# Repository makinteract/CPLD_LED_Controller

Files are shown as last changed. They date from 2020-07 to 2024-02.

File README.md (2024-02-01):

# BlinkBoard

This repository contains the hardware design of [BlinkBoard](https://blinkboard.kaist.ac.kr). An examples of software that integrates with this hardware can be found [here](https://github.com/makinteractlab/BlinkBoardApp).

This hardware is open source under the MIT license.

---

## Command Line Interface usage

This is the list of all the possible comamnds.

### Help

You can simply type `help` or use the following command to see a list of all the possible supported commands:

```js
{"cmd": "help"}  // see all supported commands
```

### Check status

Check if ready.

```js
{"cmd": "status"}    // request
{"status": "ready"}  // answer
```

### Check formware version

Check activation by passing the current month and year and see if it is <= of activation date

```js
{"cmd": "version"}  // check activateion in September 2020
{"version": "1.0"}  // answer
```

### Reset

Reset LED and outputs

```js
{"cmd": "reset"}
{"ack": "reset"}
```

### Get Input

Read A0, A1, A2 using specific number of samples (default 1 max 50);

```js
{"cmd": "analogRead"}                       // request (default samples = 1)
{"cmd": "analogRead", "samples": "5"}       // request

{"ack":"analogRead", "A0":343, "A1":371, "A2":364}  // example answer
```

### Set output

Set voltage between 0V and 4.5V on **D2**. The input value and the return voltage are clipped between 0 and 4.5V.

```js
{"cmd": "setV", "value" : "4000"}     // request
{"ack": "voltage", "value": 4000}     // answer

//clipping example
{"cmd": "setV", "value" : "5000"}     // request
{"ack": "voltage", "value": 4500}     // answer
```

**D0** and **D1** can be set HIGH/LOW or PWM.

```js
{"cmd": "setHigh", "pin": "D0"}       // request
{"cmd": "setLow", "pin": "D0"}        // request

{"ack": "setHigh", "pin": "D0"}       // answer
{"ack": "setLow", "pin": "D0"}        // answer
```

For PWM the input duty and the return voltage are clipped between 0 and 100. Pin can be **D0** or **D1**.

```js
{"cmd": "setPwm", "pin": "D0", "duty" : "90"}       // request
{"ack": "setPwm", "pin": "D0", "duty" : 90}         // answer

// clipping example
{"cmd": "setPwm", "pin": "D0", "duty" : "120"}     // request
{"ack": "setPwm", "pin": "D0", "duty" : 100}       // answer
```

### LEDs patterns

LEDs are placed in this config

```
1 -- 26
2 -- 27
3 -- 28
4 -- 29
. -- .
. -- .
. -- .
23 -- 48
24 -- 49
25 -- 50
```

Patterns:

- off
- on = steady on
- blink
- blink2 = 1/2 of blink

```js
{"cmd": "setLed", "led": "1", "pattern": "off"}
{"cmd": "setLed", "led": "1", "pattern": "on"}
{"cmd": "setLed", "led": "1", "pattern": "blink"}
{"cmd": "setLed", "led": "1", "pattern": "blink2"}

{"ack": "setLed", "led": "1", "pattern": "off"}
{"ack": "setLed", "led": "1", "pattern": "on"}
{"ack": "setLed", "led": "1", "pattern": "blink"}
{"ack": "setLed", "led": "1", "pattern": "blink2"}
```

### Set LedCmd

```js
{"cmd": "setCmdLed", "led": "vcc", "pattern": "on"}
{"cmd": "setCmdLed", "led": "gnd", "pattern": "on"}
{"cmd": "setCmdLed", "led": "a0", "pattern": "on"}
{"cmd": "setCmdLed", "led": "a1", "pattern": "on"}
{"cmd": "setCmdLed", "led": "a2", "pattern": "on"}
{"cmd": "setCmdLed", "led": "d0", "pattern": "on"}
{"cmd": "setCmdLed", "led": "d1", "pattern": "on"}
{"cmd": "setCmdLed", "led": "d2", "pattern": "on"}
{"cmd": "setCmdLed", "led": "status1", "pattern": "on"}
{"cmd": "setCmdLed", "led": "status2", "pattern": "on"}
```

### Brightness

Values of brightness between 0 and 99

```js
{"cmd": "setBrightness", "value": "1"}
{"ack": "brightness", "value": "1"}

// clipping example
{"cmd": "setBrightness", "value": "120"}
{"ack": "brightness", "value": "100"}
```

### Animate LEDs

Draw all LEDs 1-50 and vice-versa

```js
{"cmd": "animate"}
{"ack": "animate"}

// optionally put time in ms
{"cmd": "animate", value:"100"}
{"ack": "animate"}
```

### Others

Other errors

```js
{"ack":"json parse fail"}   // not valid JSON input
{"ack":"invalid command"}   // not valid command
```

---

## Hardware description

For details about the hardware design refer to the [electronic schematics](https://github.com/makinteractlab/BlinkBoard/blob/master/Altium/BlinkBoard/Project%20Outputs%20for%20BlinkBoard/BlinkBoard.PDF).

For details about how to assemble this hardware, please refer to the Hardware X paper (_link available after publication_) and the following building instructions.

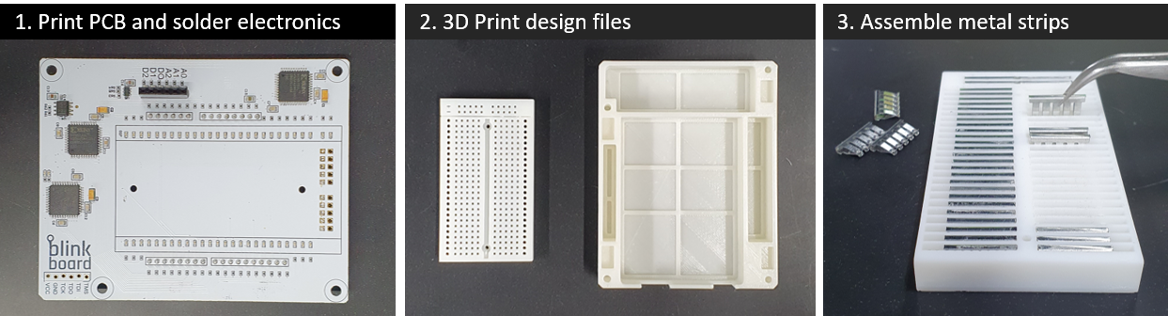
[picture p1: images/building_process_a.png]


- **Step 1**: The first step is to print the _BlinkBoard_ PCB shield using the supplied GERBER files and manually solder/assemble electronic components onto the printed shield. If placing an order from a manufacturer with a pick-and-place machine, provide them with the assembly instructions and the BOM file.
- **Step 2**: 3D print the breadboard and the case using the STL files. For better resolution/precision of the pinholes of the breadboard, it is recommended to print the model with ABS-like white resin (Accura Xtreme White 200) via an SLA (Stereolithography) 3D printer. However, the bottom case can be printed simply with PLA (PolyLactic Acid) using a Fused Deposition Modeling (FDM) machine, ensuring low cost and strength.

- **Step 3**: Assemble the metal clips placed underneath the breadboard to connect 2 four-hole female sockets on a row. These metal clips can be obtained by manually disassembling a 400-hole breadboard (e.g., Breadboard DM323).

- **Step 4**: Place the breadboard on the shield and use two M1.6 8mm bolts and nuts to tighten them.

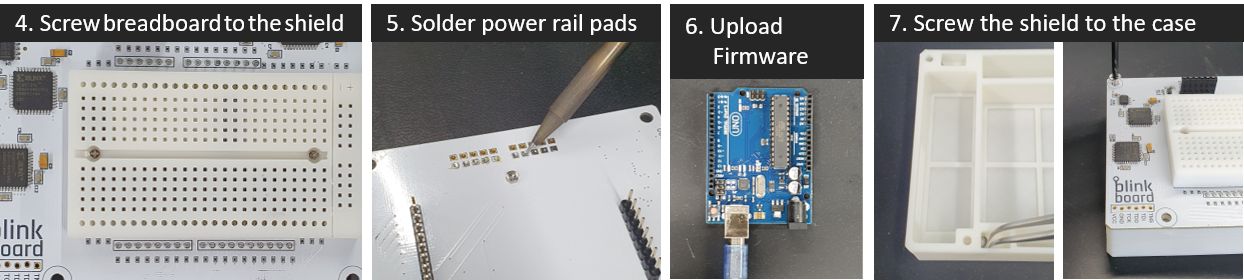
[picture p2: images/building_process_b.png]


- **Step 5**: Solder the ground rail on the bottom to share all the grounds on the _BlinkBoard_ shield. Make sure the ground socket of the breadboard is connected to this rail.

- **Step 6**: Before connecting the shield to an Arduino, upload the firmware via USB.

- **Step 7**: Insert the M3 nuts inside the housing slots of the case and fix the shield on the top of the 3D printed case using the M3 12mm bolts.

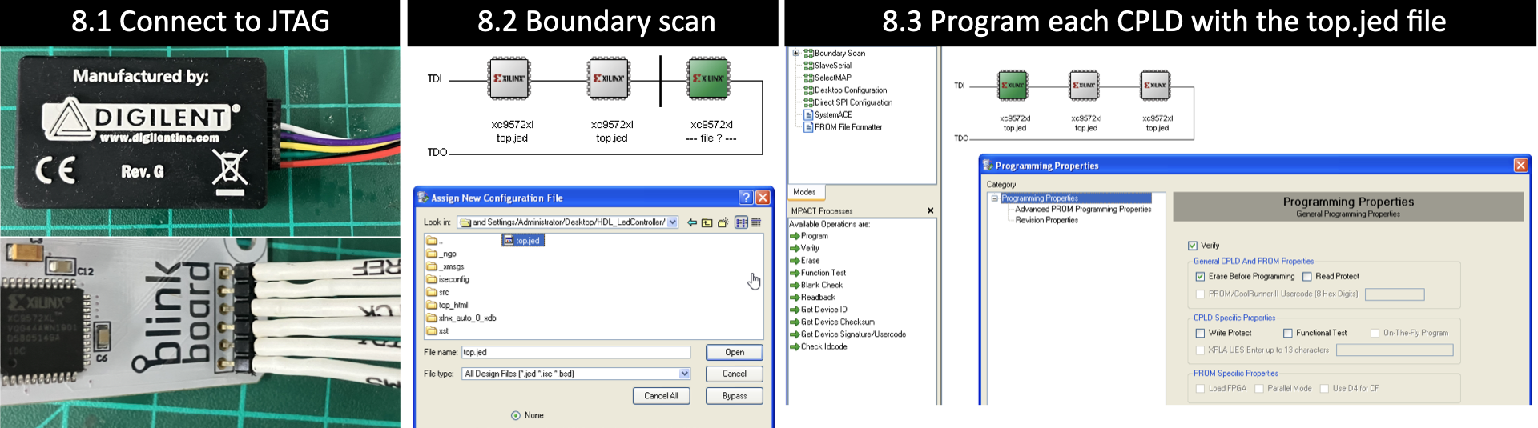
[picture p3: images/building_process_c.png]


- **Step 8**: Generate the bitstream file from the hardware-description specifications (i.e. Verilog files) using the Xilinx ISE Design Suite and upload it via JTAG on each of the CPLDs. This step can be broken down into the following sub-steps:

  1. Power up the assembled BlinkBoard hardware by plugging it into a computer via USB. Connect BlinkBoard to the [XUP USB-JTAG Programming Cable](https://digilent.com/shop/xup-usb-jtag-programming-cable/) as shown in Figure 8.

  2. 8.2: On a PC opens the application iMPACT by Xilinx. This should automatically prompt for a boundary scanning of the connected devices, and ask to choose a file to upload to the CPLDs. Simply pick the `top.jed` file in the repository, or use the ISE Design Suite to regenerate a bitstream from the source Verilog files (HDL_LedController folder). For the success of this step, ensure that the JTAG is properly connected and that the BlinkBoard is powered up.

  3. The icons of three CPLDs connected in series should be visible on the GUI. Select each one of them and click the "Program" button on the left panel to upload the bitstream on the CPLDs.

---

## References

Controlling LEDs using the [CoolRunner-II][product]. [Schematics][schematics] and [datasheet][datasheet] are provided in the links for reference.

---

## Citation

Andrea Bianchi, Kongpyung Justin Moon, Artem Dementyev, Seungwoo Je. 2024. _BlinkBoard: Guiding and monitoring circuit assembly for synchronous and remote physical computing education_. In HardwareX 2024, e00511, ISSN 2468-0672, DOI: [https://doi.org/10.1016/j.ohx.2024.e00511](https://doi.org/10.1016/j.ohx.2024.e00511).

<!-- REFERENCES -->

[product]: https://store.digilentinc.com/cmod-c2-breadboardable-coolrunner-ii-cpld-module/
[schematics]: https://reference.digilentinc.com/_media/cmod:cmod:c-mod_c295_sch.pdf
[datasheet]: https://reference.digilentinc.com/_media/cmod:cmod:cmod_rm.pdf

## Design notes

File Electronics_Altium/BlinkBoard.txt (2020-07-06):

Board Information Report
Filename     : C:\Users\Andrea\GIT\BlinkBoard\Altium\BlinkBoard\BlinkBoard.PcbDoc
Date         : 7/6/2020
Time         : 1:06:12 PM
Time Elapsed : 00:00:00

General
    Board Size, 496.316mmx149.225mm
    Components on board, 21
count : 2

Routing Information
    Routing completion, 0.00%
    Connections, 48
    Connections routed, 0
    Connections remaining, 48
count : 4

Layer, Arcs, Pads, Vias, Tracks, Texts, Fills, Regions, ComponentBodies
    Top Layer, 25, 34, 0, 0, 0, 0, 0, 0
    Int1 (GND), 0, 0, 0, 4, 0, 0, 1, 0
    Inner Sig, 0, 0, 0, 0, 0, 0, 0, 0
    Bottom Layer, 0, 0, 0, 0, 0, 0, 0, 0
    Mechanical 1, 4, 0, 0, 0, 0, 0, 0, 13
    Mechanical 2, 226, 0, 0, 104, 14, 0, 0, 0
    Multi-Layer, 0, 70, 0, 0, 0, 0, 1, 0
    Top Paste, 0, 0, 0, 0, 0, 0, 0, 0
    Top Overlay, 6, 0, 0, 84, 48, 0, 0, 0
    Top Solder, 0, 0, 0, 0, 0, 0, 0, 0
    Bottom Solder, 0, 0, 0, 0, 0, 0, 0, 0
    Bottom Overlay, 0, 0, 0, 0, 0, 0, 0, 0
    Bottom Paste, 0, 0, 0, 0, 0, 0, 0, 0
    Drill Guide, 0, 0, 0, 0, 0, 0, 0, 0
    Keep-Out Layer, 0, 0, 0, 0, 0, 0, 0, 0
    Drill Drawing, 0, 0, 0, 0, 0, 0, 0, 0
count : 16

Drill Pairs, Vias
count : 0

Non-Plated Hole Size, Pads, Vias
    2mm, 2, 0
    3.2mm, 4, 0
count : 2

Plated Hole Size, Pads, Vias
    0mm, 34, 0
    0.9mm, 32, 0
    1.1mm, 12, 0
    1.2mm, 20, 0
count : 4

Non-Plated Slot Size / Length, Pads
count : 0

Plated Slot Size / Length, Pads
count : 0

Non-Plated Square Hole Size, Pads
count : 0

Plated Square Hole Size, Pads
count : 0

Top Layer Annular Ring Size, Count
    0mm, 6
    0.4mm, 20
    0.5mm, 12
    0.6mm, 32
count : 4

Mid Layer Annular Ring Size, Count
    0mm, 6
    0.4mm, 20
    0.5mm, 12
    0.6mm, 32
count : 4

Bottom Layer Annular Ring Size, Count
    0mm, 6
    0.4mm, 20
    0.5mm, 12
    0.6mm, 32
count : 4

Pad Solder Mask, Count
    0.02mm, 30
    0.1016mm, 74
count : 2

Pad Paste Mask, Count
    0mm, 104
count : 1

Pad Pwr/Gnd Expansion, Count
    0.508mm, 104
count : 1

Pad Relief Conductor Width, Count
    0.254mm, 104
count : 1

Pad Relief Air Gap, Count
    0.254mm, 104
count : 1

Pad Relief Entries, Count
    4, 104
count : 1

Via Solder Mask, Count
count : 0

Track Width, Count
    0.08mm, 5
    0.09mm, 5
    0.1mm, 52
    0.2mm, 99
    0.5mm, 27
    1.016mm, 4
count : 6

Arc Line Width, Count
    0.08mm, 1
    0.1mm, 8
    0.2mm, 251
    1mm, 1
count : 4

Arc Radius, Count
    0.1047mm, 1
    0.2mm, 1
    0.3175mm, 1
    0.5756mm, 250
    3.7mm, 8
count : 5

Arc Degrees, Count
    180, 1
    205, 1
    360, 259
count : 3

Text Height, Count
    0.5mm, 5
    0.8mm, 1
    1mm, 3
    1.524mm, 42
    2mm, 10
    3mm, 1
count : 6

Text Width, Count
    0.1mm, 5
    0.15mm, 15
    0.254mm, 42
count : 3

Net Track Width, Count
    0.254mm, 27
count : 1

Net Via Size, Count
    1.27mm, 27
count : 1

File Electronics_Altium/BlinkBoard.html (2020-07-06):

Altium customize

# Board Information Report

Date: | | 7/6/2020
Time: | | 1:06:12 PM
Elapsed Time: | | 00:00:00
Filename: | | C:\Users\Andrea\GIT\BlinkBoard\Altium\BlinkBoard\BlinkBoard.PcbDoc
Units: | | mmmils

## Contents

Contents

Board Specification

General

Routing

Routing Information

Layer Information

Layer Information

Drill Pairs

Board Holes

Non-Plated Hole Size

Plated Hole Size

Board Slots

Non-Plated Slot Size

Plated Slot Size

Board Square Holes

Non-Plated Square Hole Size

Plated Square Hole Size

Other

Top Layer Annular Ring Size

Mid Layer Annular Ring Size

Bottom Layer Annular Ring Size

Pad Solder Mask

Pad Paste Mask

Pad Pwr/Gnd Expansion

Pad Relief Conductor Width

Pad Relief Air Gap

Pad Relief Entries

Via Solder Mask

Track Width

Arc Line Width

Arc Radius

Arc Degrees

Text Height

Text Width

Net Track Width

Net Via Size

## Board Specification

General
Board Size | 496.316mm x 149.225mm
Components on board | 21

Back to top

## Routing

Routing Information
Routing completion | 0.00%
Connections | 48
Connections routed | 0
Connections remaining | 48

Back to top

## Layer Information

Layer | Arcs | Pads | Vias | Tracks | Texts | Fills | Regions | ComponentBodies
Top Layer | 25 | 34 | 0 | 0 | 0 | 0 | 0 | 0
Int1 (GND) | 0 | 0 | 0 | 4 | 0 | 0 | 1 | 0
Inner Sig | 0 | 0 | 0 | 0 | 0 | 0 | 0 | 0
Bottom Layer | 0 | 0 | 0 | 0 | 0 | 0 | 0 | 0
Mechanical 1 | 4 | 0 | 0 | 0 | 0 | 0 | 0 | 13
Mechanical 2 | 226 | 0 | 0 | 104 | 14 | 0 | 0 | 0
Multi-Layer | 0 | 70 | 0 | 0 | 0 | 0 | 1 | 0
Top Paste | 0 | 0 | 0 | 0 | 0 | 0 | 0 | 0
Top Overlay | 6 | 0 | 0 | 84 | 48 | 0 | 0 | 0
Top Solder | 0 | 0 | 0 | 0 | 0 | 0 | 0 | 0
Bottom Solder | 0 | 0 | 0 | 0 | 0 | 0 | 0 | 0
Bottom Overlay | 0 | 0 | 0 | 0 | 0 | 0 | 0 | 0
Bottom Paste | 0 | 0 | 0 | 0 | 0 | 0 | 0 | 0
Drill Guide | 0 | 0 | 0 | 0 | 0 | 0 | 0 | 0
Keep-Out Layer | 0 | 0 | 0 | 0 | 0 | 0 | 0 | 0
Drill Drawing | 0 | 0 | 0 | 0 | 0 | 0 | 0 | 0
Total | 261 | 104 | 0 | 192 | 62 | 0 | 2 | 13

Back to top

Drill Pairs | Vias
Total | 0

Back to top

## Board Holes

Non-Plated Hole Size | Pads | Vias
2mm | 2 | 0
3.2mm | 4 | 0
Total | 6 | 0

Back to top

Plated Hole Size | Pads | Vias
0mm | 34 | 0
0.9mm | 32 | 0
1.1mm | 12 | 0
1.2mm | 20 | 0
Total | 98 | 0

Back to top

## Board Slots

Non-Plated Slot Size / Length | Pads
Total | 0

Back to top

Plated Slot Size / Length | Pads
Total | 0

Back to top

## Board Square Holes

Non-Plated Square Hole Size | Pads
Total | 0

Back to top

Plated Square Hole Size | Pads
Total | 0

Back to top

## Other

Top Layer Annular Ring Size | Count
0mm | 6
0.4mm | 20
0.5mm | 12
0.6mm | 32
Total | 70

Back to top

Mid Layer Annular Ring Size | Count
0mm | 6
0.4mm | 20
0.5mm | 12
0.6mm | 32
Total | 70

Back to top

Bottom Layer Annular Ring Size | Count
0mm | 6
0.4mm | 20
0.5mm | 12
0.6mm | 32
Total | 70

Back to top

Pad Solder Mask | Count
0.02mm | 30
0.1016mm | 74
Total | 104

Back to top

Pad Paste Mask | Count
0mm | 104
Total | 104

Back to top

Pad Pwr/Gnd Expansion | Count
0.508mm | 104
Total | 104

Back to top

Pad Relief Conductor Width | Count
0.254mm | 104
Total | 104

Back to top

Pad Relief Air Gap | Count
0.254mm | 104
Total | 104

Back to top

Pad Relief Entries | Count
4 | 104
Total | 104

Back to top

Via Solder Mask | Count
Total | 0

Back to top

Track Width | Count
0.08mm | 5
0.09mm | 5
0.1mm | 52
0.2mm | 99
0.5mm | 27
1.016mm | 4
Total | 192

Back to top

Arc Line Width | Count
0.08mm | 1
0.1mm | 8
0.2mm | 251
1mm | 1
Total | 261

Back to top

Arc Radius | Count
0.1047mm | 1
0.2mm | 1
0.3175mm | 1
0.5756mm | 250
3.7mm | 8
Total | 261

Back to top

Arc Degrees | Count
180 | 1
205 | 1
360 | 259
Total | 261

Back to top

Text Height | Count
0.5mm | 5
0.8mm | 1
1mm | 3
1.524mm | 42
2mm | 10
3mm | 1
Total | 62

Back to top

Text Width | Count
0.1mm | 5
0.15mm | 15
0.254mm | 42
Total | 62

Back to top

Net Track Width | Count
0.254mm | 27
Total | 27

Back to top

Net Via Size | Count
1.27mm | 27
Total | 27

Back to top

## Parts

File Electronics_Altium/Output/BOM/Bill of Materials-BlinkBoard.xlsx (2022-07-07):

Designator | Packaging | Supplier Part Number 1 | Comment | Description | Manufacturer 1 | Manufacturer Part Number 1 | Quantity | Supplier Currency 1 | Supplier Order Qty 1 | Supplier Unit Price 1
C1, C2, C3 | Tape and Reel | 399-3688-6-ND | 100u | 100uF Solid MnO2 Tantalum Capacitor, 4 V +/-20%, T491 Series | KEMET | T491A107M004AT | 3 | USD | 3 | 0.73
C4, C5, C6, C7, C8, C9, C10, C11, C12 | Tape and Reel | 311-3553-6-ND | 47n | Cap Ceramic 0.047uF 50V X7R 5% SMD 0805 125C Paper T/R | Yageo | CC0805JRX7R9BB473 | 9 | USD | 9 | 0.17
C13, C16 | Tape and Reel | 311-1358-6-ND | 1u | CERAMIC CAPACITOR, 1UF, 25V, Y5V, +80, -20%, 0805, FULL REEL; Product Range:CC Series; Capacitance:1 F; Capacitance Tolerance:+80%, -20%; Dielectric Characteristic:Y5V; Voltage Rating:25V; Ceramic Capacitor Case:0805 [2012 Metric] ;RoHS Compliant: Yes | Yageo | CC0805ZRY5V8BB105 | 2 | USD | 2 | 0.14
C14 | Tape and Reel | 311-1703-6-ND | 10n | Cap Ceramic 0.01uF 10V X7R 10% SMD 0402 125C Paper T/R | Yageo | CC0402KRX7R6BB103 | 1 | USD | 1 | 0.1
C15 | Tape and Reel | 311-2084-6-ND | 10u | Cap Ceramic 10uF 6.3V X5R 10% SMD 0805 85C Paper T/R | Yageo | CC0805KRX5R5BB106 | 1 | USD | 1 | 0.21
D1, D2, D3, D4, D5, D6, D7, D8, D9, D10, D11, D12, D13, D14, D15, D16, D17, D18, D19, D20, D21, D22, D23, D24, D25, D26, D27, D28, D29, D30, D31, D32, D33, D34, D35, D36, D37, D38, D39, D40, D41, D42, D43, D44, D45, D46, D47, D48, D49, D50, D51, D52, D53, D54, D55, D56, D57, D58, D59, D60 | Tape and Reel | VLMS1500-GS08DKR-ND | LED0402_RED | Led red | Vishay | VLMS1500-GS08 | 60 | USD | 60 | 0.322
R1, R2, R3, R4, R5, R6, R7, R8, R9, R10, R11, R12, R13, R14, R15, R16, R17, R18, R19, R20, R21, R22, R23, R24, R25, R26, R27, R28, R29, R30, R31, R32, R33, R34, R35, R36, R37, R38, R39, R40, R41, R42, R43, R44, R45, R46, R47, R48, R49, R50, R51, R52, R53, R54, R55, R56, R57, R58, R59, R60 | Tape and Reel | 311-62.0LRDKR-ND | 62 | RES SMD 62 OHM 1% 1/16W 0402 | Yageo | RC0402FR-0762RL | 60 | USD | 60 | 0.016
R61 | Tape and Reel | 311-47KJRDKR-ND | 47k | YAGEO - RC0402JR-0747KL - SMD Chip Resistor, 0402 [1005 Metric], 47 kohm, RC Series, 50 V, Thick Film, 63 mW | Yageo | RC0402JR-0747KL | 1 | USD | 1 | 0.1
R62 | Tape and Reel | 311-120KJRDKR-ND | 120k | RES SMD 120K OHM 5% 1/16W 0402 | Yageo | RC0402JR-07120KL | 1 | USD | 1 | 0.1
R63, R64, R65 | Tape and Reel | YAG1249DKR-ND | 10k | RES SMD 10K OHM 1% 1/16W 0402 | Yageo | RC0402FR-0710KP | 3 | USD | 3 | 0.1
U1, U2, U3 | Tray | 122-1448-ND | XC9572XL-10VQG44C | XILINX - XC9572XL-10VQG44C. - CPLD, 72 MACROCELL, 3.3V, 44VQFP | Xilinx | XC9572XL-10VQG44C | 3
U4 | Tape and Reel | 296-6501-6-ND | NE555DR | TEXAS INSTRUMENTS NE555DR. TIMER, SINGLE, 500KHZ, 16V, SOIC-8 | Texas Instruments | NE555DR | 1 | USD | 1 | 0.46
U5 | Tape and Reel | MCP4725A0T-E/CHDKR-ND | MCP4725A0T-E/CH (2) | DAC 1-CH Resistor-String 12-bit 6-Pin SOT-23A T/R | Microchip | MCP4725A0T-E/CH | 1 | USD | 1 | 1.28

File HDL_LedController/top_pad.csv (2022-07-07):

Release 8.1i - Fit P.20131013
Copyright(c) 1995-2003 Xilinx Inc. All rights reserved
7- 7-2022 4:23PM
NOTE: This file is designed to be imported into a spreadsheet program
such as Microsoft Excel for viewing | printing and sorting. The comma ' | '
character is used as the data field separator.
This file is also designed to support parsing.
Input file: top.ngd
output file: top_pad.csv
Part type: xc9572xl
Speed grade: -5
Package: vq44
Pinout by Pin Number:
----- | ----- | ----- | ----- | ----- | ----- | ----- | ----- | ----- | -----
Pin Number | Signal Name | Pin Usage | Pin Name | Direction | IO Standard | IO Bank Number | {blank} | Slew Rate | Termination | {blank} | Voltage | Constraint
P1 | TIE |  | I/O/GCK3
P2 | LED<19> | O | I/O | OUTPUT
P3 | LED<18> | O | I/O | OUTPUT
P4 | GND |  | GND
P5 | LED<17> | O | I/O | OUTPUT
P6 | LED<16> | O | I/O | OUTPUT
P7 | LED<15> | O | I/O | OUTPUT
P8 | LED<14> | O | I/O | OUTPUT
P9 | TDI |  | TDI
P10 | TMS |  | TMS
P11 | TCK |  | TCK
P12 | LED<13> | O | I/O | OUTPUT
P13 | LED<12> | O | I/O | OUTPUT
P14 | LED<11> | O | I/O | OUTPUT
P15 | VCC |  | VCCINT
P16 | LED<10> | O | I/O | OUTPUT
P17 | GND |  | GND
P18 | LED<9> | O | I/O | OUTPUT
P19 | LED<8> | O | I/O | OUTPUT
P20 | LED<7> | O | I/O | OUTPUT
P21 | LED<6> | O | I/O | OUTPUT
P22 | LED<5> | O | I/O | OUTPUT
P23 | LED<4> | O | I/O | OUTPUT
P24 | TDO |  | TDO
P25 | GND |  | GND
P26 | VCC |  | VCCIO
P27 | LED<3> | O | I/O | OUTPUT
P28 | LED<2> | O | I/O | OUTPUT
P29 | LED<1> | O | I/O | OUTPUT
P30 | LED<0> | O | I/O | OUTPUT
P31 | TIE |  | I/O
P32 | TIE |  | I/O
P33 | TIE |  | I/O/GSR
P34 | TIE |  | I/O/GTS2
P35 | VCC |  | VCCINT
P36 | TIE |  | I/O/GTS1
P37 | PATTERN_555 | I | I/O | INPUT
P38 | PWM | I | I/O | INPUT
P39 | DATA | I | I/O | INPUT
P40 | CLK | I | I/O | INPUT
P41 | LATCH | I | I/O | INPUT
P42 | RESET | I | I/O | INPUT
P43 | TIE |  | I/O/GCK1
P44 | TIE |  | I/O/GCK2
To preserve the pinout above for future design iterations in
Project Navigator simply execute the (Lock Pins) process
located under the (Implement Design) process in a toolbox named
(Optional Implementation Tools) or invoke PIN2UCF from the
command line. The location constraints will be written into your
specified UCF file

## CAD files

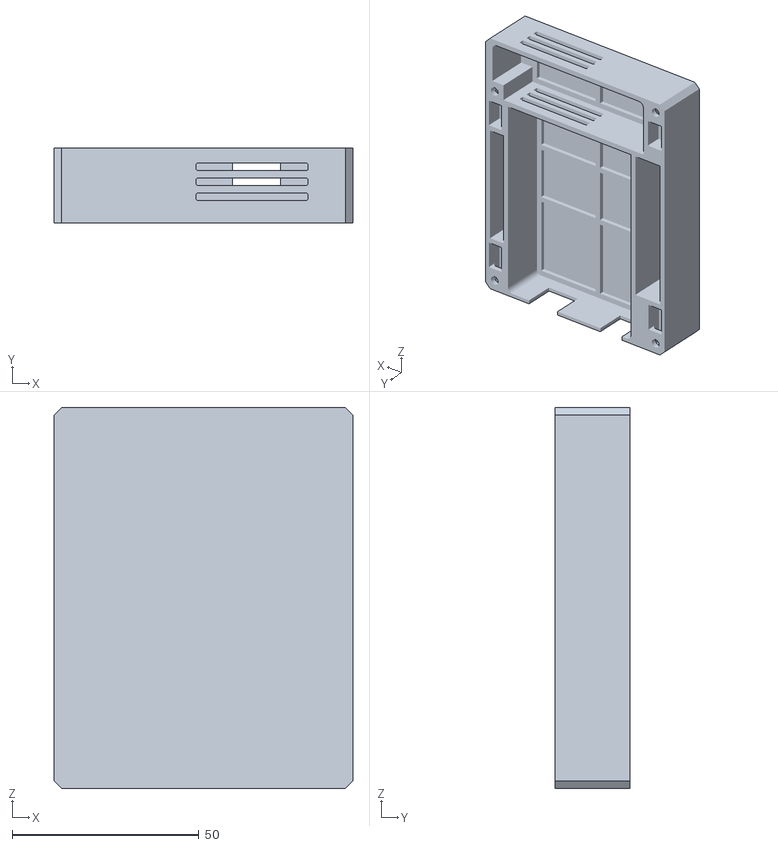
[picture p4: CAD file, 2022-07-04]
3D_models/Case.stl
80.0 x 20.0 x 102.0

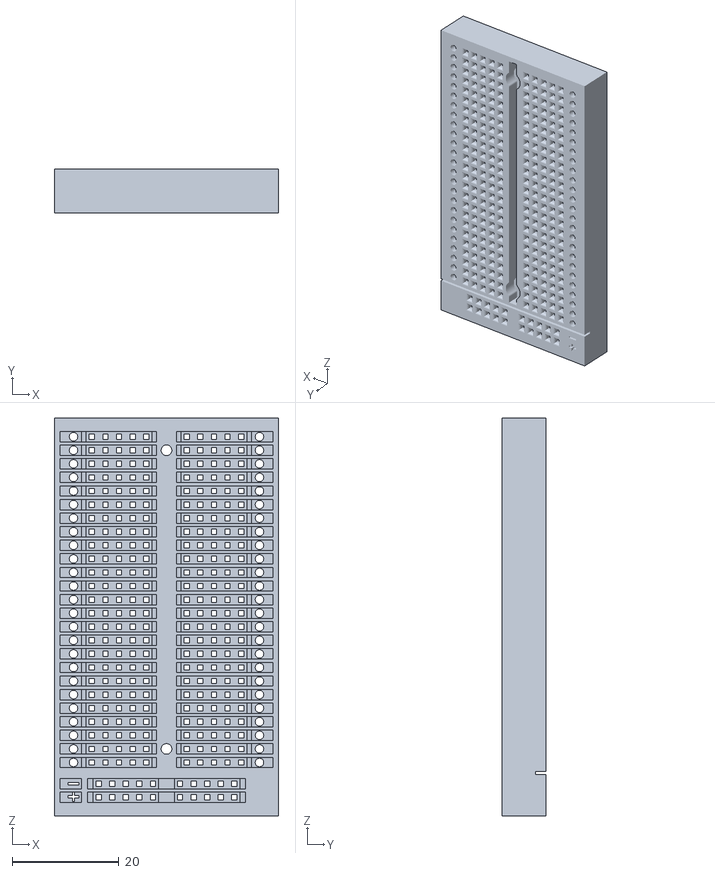
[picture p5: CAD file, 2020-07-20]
3D_models/Breadboard.stl
42.0 x 8.30 x 74.5

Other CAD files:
3D_models/Breadboard_fusion.f3d
3D_models/Case_fusion.f3d

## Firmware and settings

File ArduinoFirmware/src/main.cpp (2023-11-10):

#include <Arduino.h>

// Libs
#include <ArduinoJson.h>
#include <Adafruit_MCP4725.h>

// Constants
#include "constants.hpp"

// Types
enum class CmdLed
{
  VCC_LED,
  GND_LED,
  A0_LED,
  A1_LED,
  A2_LED,
  D0_LED,
  D1_LED,
  D2_LED,
  STATUS_LED,
  ERROR_LED
};

// Forward declarations
// Init
void initialize();
void reset();

// Parse
void parse(const String &buffer);
void sendJson();
void invalidCommand();
void helpText();

// InOut
uint32_t setVoltage(uint32_t mV);
void readAnalogSamples(uint16_t &a0, uint16_t &a1, uint16_t &a2, uint8_t samples);
uint16_t dutyCycleToByte(uint16_t value);
uint16_t analogReadingToVoltage(uint16_t val);

// LED ctrl
uint16_t setBrigtness(uint16_t brightness);

bool sendLedCommand(uint8_t ledNumber, uint8_t chipNumber, String &state);
bool setLed(uint8_t led, String &state);
bool setCmdLed(CmdLed led, String &state);
bool setCmdLed(String &ledType, String &state);
void animateLed(uint8_t delayMs = ANIMATION_DELAYMS);
void allLedOff();
void setStatus(bool on);
void setErrorStatus(bool on);

// Globals
Adafruit_MCP4725 dac;
StaticJsonDocument<BUFFER_SIZE> json;
String buffer = "";

// Main
void setup()
{
  initialize();
  reset();

  delay(1000);
  animateLed();
}

void loop()
{
  while (Serial.available())
  {
    char inChar = (char)Serial.read();
    if (inChar == '\n')
    {
      parse(buffer);
      buffer = "";
    }
    else
    {
      buffer += inChar;
    }
  }
}

// Helpers

void initialize()
{
  Serial.begin(BAUD_RATE);

  pinMode(LATCH1, OUTPUT);
  pinMode(LATCH2, OUTPUT);
  pinMode(LATCH3, OUTPUT);
  pinMode(DATA, OUTPUT);
  pinMode(CLK, OUTPUT);
  pinMode(RESET, OUTPUT);

  pinMode(OUTPUT_D0, OUTPUT);
  pinMode(OUTPUT_D1, OUTPUT);

  // DAC
  dac.begin(MCP4725A0);

  // Default brightness
  setBrigtness(DEFAULT_BRIGHTNESS);
}

void reset()
{
  digitalWrite(RESET, LOW);
  setVoltage(MIN_VOLTAGE);
  digitalWrite(OUTPUT_D0, LOW);
  digitalWrite(OUTPUT_D1, LOW);

  // ready for input
  digitalWrite(RESET, HIGH);

  // Out voltage
  setVoltage(0);

  // all off
  allLedOff();

  // status and error
  setStatus(true);
  setErrorStatus(false);
}

void parse(const String &buffer)
{
  if (buffer.indexOf("help") >= 0)
  {
    helpText();
    return;
  }

  DeserializationError error = deserializeJson(json, buffer);

  // Reset for next instruction errors status led
  setErrorStatus(false);

  // Test if parsing succeeds.
  if (error)
  {
    setErrorStatus(true);
    json.clear();
    json["ack"] = "json parse fail";
    sendJson();
    return;
  }

  // Parse JSON commands
  // READY
  if (json["cmd"] == F("status"))
  {
    json.clear();
    json["status"] = "ready";
    sendJson();
  }
  // HELP
  else if (json["cmd"] == F("help"))
  {
    helpText();
  }
  // VERSION
  else if (json["cmd"] == F("version"))
  {
    json.clear();
    json["version"] = VERSION;
    sendJson();
  }
  // RESET
  else if (json["cmd"] == F("reset"))
  {
    reset();

    json.clear();
    json["ack"] = "reset";
    sendJson();
  }
  // Animate
  else if (json["cmd"] == F("animate"))
  {
    long val = json["value"].as<long>();
    if (val > 0)
      animateLed(val);
    else
      animateLed();

    json.clear();
    json["ack"] = "animate";
    sendJson();
  }
  // READ ANALOG
  else if (json["cmd"] == F("analogRead"))
  {
    long samples = json["samples"].as<long>();
    if (samples == 0)
      samples = 1; // default if not specified

    uint16_t a0, a1, a2;
    readAnalogSamples(a0, a1, a2, samples);

    json.clear();
    json["ack"] = "analogRead";
    json["A0"] = a0;
    json["A1"] = a1;
    json["A2"] = a2;
    sendJson();
  }
  // SET HIGH
  else if (json["cmd"] == F("setHigh"))
  {
    String pin = json["pin"].as<String>();
    if (pin == "D0")
      digitalWrite(OUTPUT_D0, HIGH);
    else if (pin == "D1")
      digitalWrite(OUTPUT_D1, HIGH);
    else
    {
      invalidCommand();
      return;
    }

    json.clear();
    json["ack"] = "setHigh";
    json["pin"] = pin;
    sendJson();
  }
  // SET LOW
  else if (json["cmd"] == F("setLow"))
  {
    String pin = json["pin"].as<String>();
    if (pin == "D0")
      digitalWrite(OUTPUT_D0, LOW);
    else if (pin == "D1")
      digitalWrite(OUTPUT_D1, LOW);
    else
    {
      invalidCommand();
      return;
    }

    json.clear();
    json["ack"] = "setLow";
    json["pin"] = pin;
    sendJson();
  }
  // SET PWM
  else if (json["cmd"] == F("setPwm"))
  {
    String pin = json["pin"].as<String>();
    uint16_t duty = json["duty"].as<long>();
    if (duty > 100)
      duty = 100;

    if (pin == "D0")
      analogWrite(OUTPUT_D0, dutyCycleToByte(duty));
    else if (pin == "D1")
      analogWrite(OUTPUT_D1, dutyCycleToByte(duty));
    else
    {
      invalidCommand();
      return;
    }

    json.clear();
    json["ack"] = "setPwm";
    json["pin"] = pin;
    json["duty"] = duty;
    sendJson();
  }
  // SET VOLTAGE
  else if (json["cmd"] == F("setV"))
  {
    long val = json["value"].as<long>();
    val = setVoltage(val);

    json.clear();
    json["ack"] = "voltage";
    json["value"] = val;
    sendJson();
  }
  // SET LED
  else if (json["cmd"] == F("setLed"))
  {
    long led = json["led"].as<long>();
    String ptrn = json["pattern"].as<String>();

    if (setLed(led, ptrn))
    {
      json.clear();
      json["ack"] = "setLed";
      sendJson();
    }
    else
    {
      invalidCommand();
    }
  }
  // SET LEDCMD
  else if (json["cmd"] == F("setCmdLed"))
  {
    String led = json["led"].as<String>();
    String ptrn = json["pattern"].as<String>();

    if (setCmdLed(led, ptrn))
    {
      json.clear();
      json["ack"] = "setCmdLed";
      sendJson();
    }
    else
    {
      invalidCommand();
    }
  }
  // SET LED BRIGHTNESS
  else if (json["cmd"] == F("setBrightness"))
  {
    long val = json["value"].as<long>();
    if (val > 100)
      val = 100;
    val = setBrigtness(val);

    json.clear();
    json["ack"] = "brightness";
    json["value"] = val;
    sendJson();
  }
  // ELSE
  else
  {
    invalidCommand();
  }
}

void sendJson()
{
  serializeJson(json, Serial);
  Serial.println("");
}

void invalidCommand()
{
  setErrorStatus(true);
  json.clear();
  json["ack"] = "invalid command";
  sendJson();
}

void helpText()
{
  Serial.println(F("List of available commands of the form {\"cmd\": COMMAND}\n"));
  Serial.println(F("\"status\" - check the status of the hardware"));
  Serial.println(F("\"version\" - get current BlinkBoard firmware version"));
  Serial.println(F("\"reset\" - reset LEDs and output"));
  Serial.println(F("\"analogRead\" - read from analog PINs A0, A1, A2"));
  Serial.println(F("\"setV\" - set voltage between 0V and 4.5V on D2"));
  Serial.println(F("\"setHigh\" - set HIGH on D0 or D1"));
  Serial.println(F("\"setLow\" - set LOW on D0 or D1"));
  Serial.println(F("\"setPwm\" - set a PWM output on D0 or D1"));
  Serial.println(F("\"setLed\" - choose a pattern for a specific LED of the breadboard"));
  Serial.println(F("\"setCmdLed\" - set a pattern for a control LED"));
  Serial.println(F("\"setBrightness\" - set brightness of LEDs"));
  Serial.println(F("\"animate\" - animate the LEDs"));
}

uint32_t setVoltage(uint32_t mV)
{
  // clip
  if (mV > MAX_VOLTAGE)
    mV = MAX_VOLTAGE;

  uint32_t v = map(mV, 0, MAX_VOLTAGE, 0, 4095);
  dac.setVoltage(v, false); // to do the convertion
  return mV;
}

void readAnalogSamples(uint16_t &a0, uint16_t &a1, uint16_t &a2, uint8_t samples)
{
  a0 = analogReadingToVoltage(analogRead(INPUT_A0));
  a1 = analogReadingToVoltage(analogRead(INPUT_A1));
  a2 = analogReadingToVoltage(analogRead(INPUT_A2));

  if (samples == 1)
    return;
  // else
  if (samples > MAX_SAMPLES)
    samples = MAX_SAMPLES;

  for (uint8_t i = 0; i < samples - 1; i++) // do the remaining samples-1 cases
  {
    a0 += analogReadingToVoltage(analogRead(INPUT_A0));
    a1 += analogReadingToVoltage(analogRead(INPUT_A1));
    a2 += analogReadingToVoltage(analogRead(INPUT_A2));
  }
  a0 /= samples;
  a1 /= samples;
  a2 /= samples;
}

// LED number 0-19
// chipNumber: 1,2,3
// state: on, off, blink, blink2
bool sendLedCommand(uint8_t ledNumber, uint8_t chipNumber, String &state)
{
  if (ledNumber > 19)
    return false;

  uint8_t latch = 0;
  switch (chipNumber)
  {
  case 1:
    latch = LATCH1;
    break;
  case 2:
    latch = LATCH2;
    break;
  case 3:
    latch = LATCH3;
    break;
  default:
    return false;
  }

  uint8_t op = 0; // off
  if (state == F("off"))
    op = 0;
  else if (state == F("on"))
    op = 1;
  else if (state == F("blink"))
    op = 2;
  else if (state == F("blink2"))
    op = 3;
  else
    return false;

  digitalWrite(latch, LOW);
  shiftOut(DATA, CLK, MSBFIRST, ledNumber | (op << 5));
  digitalWrite(latch, HIGH);
  return true;
}

bool setLed(uint8_t led, String &state)
{
  if (led < 1 || led > 50)
    return false;
  // Chip 1: rows 1-18 => pins 2 - 19
  bool result = false;
  if (led <= 18)
  {
    result = sendLedCommand(led + 1, 1, state);
  }
  // Chip 2: rows 19 - 25 => pins 0 - 6
  else if (led <= 25)
  {
    result = sendLedCommand(led - 19, 2, state);
  }
  // Chip 3: rows 26 - 37   => pins 10 - 0
  else if (led <= 37)
  {
    result = sendLedCommand(37 - led, 3, state);
  }
  else
  {
    // Chip 2: rows 38 - 50 => pins 19 - 7
    result = sendLedCommand(38 - led + 19, 2, state);
  }

  return result;
}

bool setCmdLed(String &ledType, String &state)
{
  if (ledType == F("vcc"))
    sendLedCommand(0, 1, state);
  else if (ledType == F("gnd"))
    sendLedCommand(1, 1, state);
  else if (ledType == F("a0"))
    sendLedCommand(12, 3, state);
  else if (ledType == F("a1"))
    sendLedCommand(13, 3, state);
  else if (ledType == F("a2"))
    sendLedCommand(14, 3, state);
  else if (ledType == F("d0"))
    sendLedCommand(15, 3, state);
  else if (ledType == F("d1"))
    sendLedCommand(16, 3, state);
  else if (ledType == F("d2"))
    sendLedCommand(17, 3, state);
  else if (ledType == F("status1"))
    sendLedCommand(18, 3, state);
  else if (ledType == F("status2"))
    sendLedCommand(19, 3, state);
  else
    return false;

  return true;
}

bool setCmdLed(CmdLed led, String &state)
{
  switch (led)
  {
  case CmdLed::VCC_LED:
    sendLedCommand(0, 1, state);
    break;
  case CmdLed::GND_LED:
    sendLedCommand(1, 1, state);
    break;
  case CmdLed::A0_LED:
    sendLedCommand(12, 3, state);
    break;
  case CmdLed::A1_LED:
    sendLedCommand(13, 3, state);
    break;
  case CmdLed::A2_LED:
    sendLedCommand(14, 3, state);
    break;
  case CmdLed::D0_LED:
    sendLedCommand(15, 3, state);
    break;
  case CmdLed::D1_LED:
    sendLedCommand(16, 3, state);
    break;
  case CmdLed::D2_LED:
    sendLedCommand(17, 3, state);
    break;
  case CmdLed::STATUS_LED:
    sendLedCommand(18, 3, state);
    break;
  case CmdLed::ERROR_LED:
    sendLedCommand(19, 3, state);
    break;
  default:
    return false; // wrong option
  }
  return true;
}

// value is between
uint16_t dutyCycleToByte(uint16_t value)
{
  if (value > 100)
    value = 100;
  return value * 255 / 100;
}

// brightness is 0-100
uint16_t setBrigtness(uint16_t brightness)
{
  if (brightness > 100)
    brightness = 100;
  analogWrite(PWM_PIN, brightness * 255 / 100);
  return brightness;
}

void animateLed(uint8_t delayMS)
{
  // left
  String on = "on";
  String off = "off";

  // down
  for (int i = 1; i <= ROWS; i++)
  {
    setLed(i, on);
    setLed(i + ROWS, on);
    delay(delayMS);
  }

  for (int i = 1; i <= ROWS; i++)
  {
    setLed(i, off);
    setLed(i + ROWS, off);
    delay(delayMS);
  }
}

void allLedOff()
{
  String off = "off";

  for (int i = 0; i <= ROWS * 2; i++)
  {
    setLed(i, off);
  }

  // Command lED
  setCmdLed(CmdLed::VCC_LED, off);
  setCmdLed(CmdLed::GND_LED, off);
  setCmdLed(CmdLed::A0_LED, off);
  setCmdLed(CmdLed::A1_LED, off);
  setCmdLed(CmdLed::A2_LED, off);
  setCmdLed(CmdLed::D0_LED, off);
  setCmdLed(CmdLed::D1_LED, off);
  setCmdLed(CmdLed::D2_LED, off);
  setCmdLed(CmdLed::STATUS_LED, off);
  setCmdLed(CmdLed::ERROR_LED, off);
}

void setStatus(bool on)
{
  String s1 = F("on");
  String s2 = F("off");
  if (on)
    setCmdLed(CmdLed::STATUS_LED, s1);
  else
    setCmdLed(CmdLed::STATUS_LED, s2);
}

void setErrorStatus(bool on)
{
  String s1 = F("on");
  String s2 = F("off");
  if (on)
    setCmdLed(CmdLed::ERROR_LED, s1);
  else
    setCmdLed(CmdLed::ERROR_LED, s2);
}

uint16_t analogReadingToVoltage(uint16_t val)
{
  return map(val, 0, 1025, 0, 5000);
}

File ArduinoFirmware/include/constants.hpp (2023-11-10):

#ifndef __CONSTANTS__H__
#define __CONSTANTS__H__

// CPLD CONTROL
#define LATCH1 8
#define LATCH2 9
#define LATCH3 10
#define DATA 11
#define CLK 12
#define RESET 13

// INPUT OUTPUT CONTTROL
#define INPUT_A0 A0
#define INPUT_A1 A1
#define INPUT_A2 A2
#define OUTPUT_D0 5
#define OUTPUT_D1 6
#define PWM_PIN 3

// ADDRESSES
#define MCP4725A0 0x60
// #define EEPROM_ADDRESS 0

// SETTINGS
#define DEFAULT_BRIGHTNESS 20
#define BUFFER_SIZE 128
#define MIN_VOLTAGE 0
#define MAX_VOLTAGE 4800
#define MAX_SAMPLES 50
#define ANIMATION_DELAYMS 30
#define ROWS 25

#define VERSION F("1.2")
#define BAUD_RATE 115200

#endif

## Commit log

2020-06-30 Working but exceding 64 macrocells - verrsion 2
    [top_pad.csv]
2020-06-30 Working but exceding 64 macrocells - or max 16 LED
    [top_pad.csv]
2020-06-30 16 LED working
2020-06-30 Working with 19 LED - 100% macrocells
2020-07-01 Working with 70 macrocells - 21 LEDs and 2 patterns
2020-07-01 Working with 72 macrocells and 21 LED and 2 pattenrs
2020-07-01 Working with 20 LEDs and 2 patterns on XC9572XL
2020-07-01 Added altium and arduino test code
    [LEDcontroller.SchDoc, LightBoard.PrjPcb, LightBoard_v1.0.PcbDoc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]
2020-07-02 Added BOM
    [BOM.xls, LEDcontroller.SchDoc, LightBoard.PrjPcb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]
2020-07-06 Renamed and routed
    [BOM.xls, LEDcontroller.SchDoc, LightBoard_v1.0.PcbDoc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]
2020-07-06 Added designators
    [BlinkBoard.PcbDoc, BlinkBoard.PcbLib, BlinkBoard.PrjPcb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]
2020-07-08 Final board
    [BlinkBoard.SchDoc, BlinkBoard.SchLib, LEDcontroller.SchDoc]
2020-07-08 Gerbers finalized
2020-07-09 Updated tantalum cap footprint and symbol
    [BlinkBoard.SchLib, LEDcontroller.SchDoc]
2020-07-17 Add logo file and 3D model file
    - create logo file, add logo illustate file and jpg file
    - create 3D model file, add stl file for 3D printing and stp file for rendering
    [20200707_basic_thin_with LED(25).stl, 20200707_basic_thin_with LED(25).stp]
2020-07-17 Revert "Add logo file and 3D model file"
    This reverts commit 60fdc2c7a3369d20edaccebc9f64261d91d72313.
    [20200707_basic_thin_with LED(25).stl, 20200707_basic_thin_with LED(25).stp]
2020-07-17 Add logo files and 3D model files
    - created logo file, add illustrator file and jpg file
    - created 3D model file, add stl file for the printing and stp file for the rendering
    [20200707_basic_thin_with LED(25).stl, 20200707_basic_thin_with LED(25).stp]
2020-07-23 Added snippet Arduino serial
2020-08-03 Fixed DAC and Analog Readings
    [constants.hpp, main.cpp]
2020-08-07 Added pick and place
    [Bill of Materials-BlinkBoard.xls, Pick Place for BlinkBoard.csv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]
2020-08-13 New HDL allows PWM on blinking pins
2022-07-04 Restructuring folders
    [20200707_basic_thin_with LED(25).stp, Bill of Materials-BlinkBoard.xls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]
2022-07-04 Adding Fusion Models
    [Breadboard_fusion.f3d, Case_fusion.f3d]
2022-07-07 HDL verified
    [top_pad.csv]
2022-07-07 Cleaned folder
    [Bill of Materials-BlinkBoard.xls, Bill of Materials-BlinkBoard.xlsx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]
